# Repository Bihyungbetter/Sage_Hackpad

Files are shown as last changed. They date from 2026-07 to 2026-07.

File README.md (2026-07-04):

# Sage Hackpad

## Overview

I'm Michael, and this is my Macropad! It is inspired by the Sage Agent from Valorant. It features 10 inputs, has 9 switches, one knob, and an OLED display! 
I would like to solder it myself! 

# BOM:
- 1x Seeed XIAO RP2040
- 1x PCB
- 2x 4.7k resistor
- 9x SK6812 MINI-E LEDs
- 9x Cherry MX Switches
- 9x Through-hole 1N4148 Diodes
- 9x Blank DSA Keycaps
- 1x 0.91" 128x32 OLED Display
- 1x EC11 Rotary Encoder
- 6x M3x16mm screws
- 6x M3x5mx4mm heatset inserts

# Photos!
Master Assembly (3)
Master Assembly (4)



# Colors
If possible, could I get each part of the case in its respective colors?

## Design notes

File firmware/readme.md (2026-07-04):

# sage_hackpad

sage_hackpad

*A short description of the keyboard/project*

* Keyboard Maintainer: [Michael](https://github.com/BihyungBetter)
* Hardware Supported: *The PCBs, controllers supported*
* Hardware Availability: *Links to where you can find this hardware*

Make example for this keyboard (after setting up your build environment):

    make sage_hackpad:default

Flashing example for this keyboard:

    make sage_hackpad:default:flash

See the [build environment setup](https://docs.qmk.fm/#/getting_started_build_tools) and the [make instructions](https://docs.qmk.fm/#/getting_started_make_guide) for more information. Brand new to QMK? Start with our [Complete Newbs Guide](https://docs.qmk.fm/#/newbs).

## Bootloader

Enter the bootloader in 3 ways:

* **Bootmagic reset**: Hold down the key at (0,0) in the matrix (usually the top left key or Escape) and plug in the keyboard
* **Physical reset button**: Briefly press the button on the back of the PCB - some may have pads you must short instead
* **Keycode in layout**: Press the key mapped to `QK_BOOT` if it is available

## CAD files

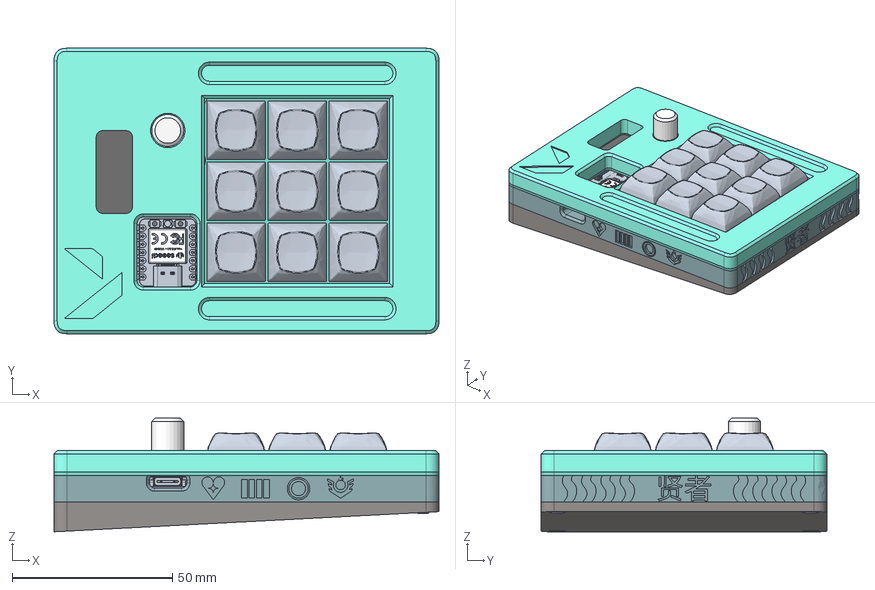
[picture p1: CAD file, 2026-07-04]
cad/Master Assembly.step
120.0 x 89.0 x 35.4 mm
MX Mount v1 x 9
DSA V4 1x1 v4 x 9
Bottom Case
92095A184_18-8 Stainless Steel Button Head Hex-Drive Screw x 4
HackPad_silkscreen x 158
D_DO-35_SOD27_P7.62mm_Horizontal_8 x 2
HackPad_copper x 36
HackPad_PCB
HackPad_soldermask x 2
D_DO-35_SOD27_P7.62mm_Horizontal_7 x 2
D_DO-35_SOD27_P7.62mm_Horizontal_5 x 2
D_DO-35_SOD27_P7.62mm_Horizontal_4 x 2
R_0805_2012Metric
R_0805_2012Metric_1
D_DO-35_SOD27_P7.62mm_Horizontal_3 x 2
D_DO-35_SOD27_P7.62mm_Horizontal_2 x 2
D_DO-35_SOD27_P7.62mm_Horizontal_1 x 2
D_DO-35_SOD27_P7.62mm_Horizontal x 2
D_DO-35_SOD27_P7.62mm_Horizontal_6 x 2
Aligner
RESC-0603_1 x 3
RESC-0603_2 x 3
RESC-0603 x 3
RESC-0603_7 x 3
2SD0601A x 4
RESC-0603_8 x 3
RESC-0603_3 x 3
Pin Header 4 x 1 TH 2.54mm Pitch x 8
RESC-0603_12 x 3
RESC-0603_9 x 3
RESC-0603_6 x 3
RESC-0603_4 x 3
RESC-0603_10 x 3
RESC-0603_5 x 3
RESC-0603_11 x 3
OLED_0.91_128x32
Seeed Studio XIAO RP2040 v26 x 36
type-c v2 x 24
VSS
VDD
main x 16
smd_button v3(Mirror)
DIN
DOUT
smd_button v3
Top Case
Middle Case
EC11-Housing-SMD x 7
EC11-Shaft-F
EC11-Base

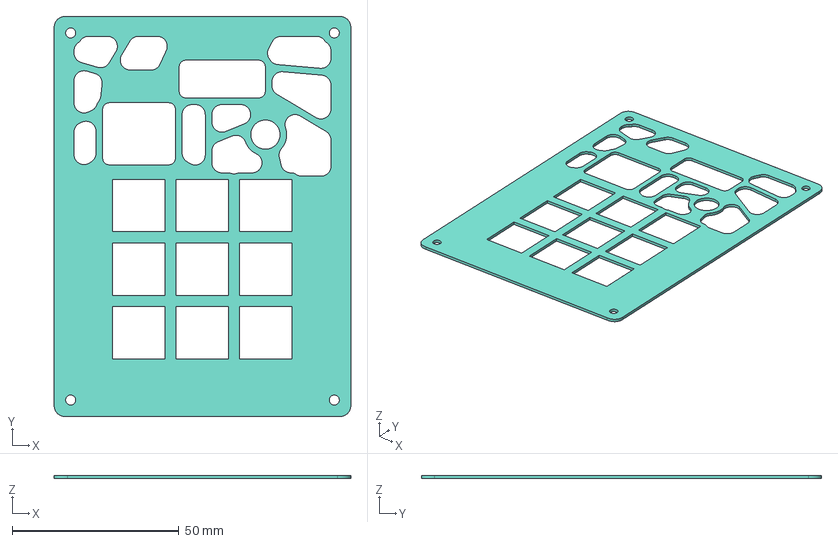
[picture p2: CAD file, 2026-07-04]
production/Part Studio 1 - Middle Case.step
89.0 x 120.0 x 1.00 mm

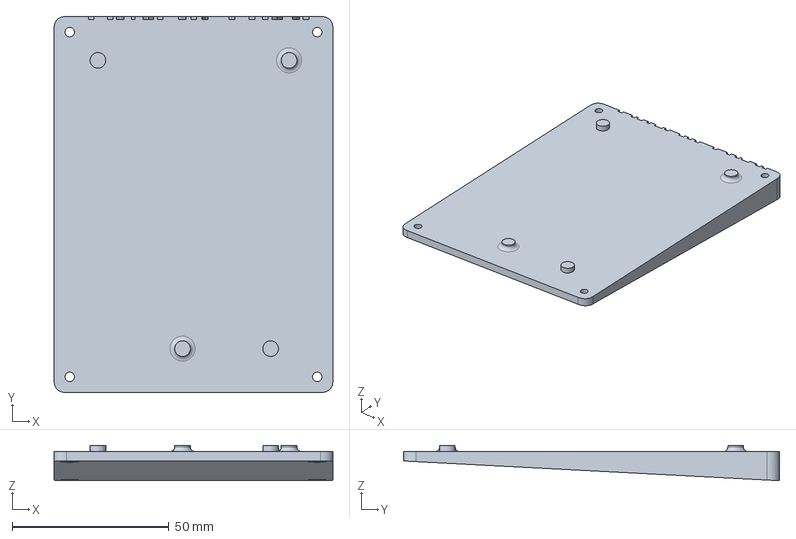
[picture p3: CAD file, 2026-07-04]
production/Part Studio 1 - Top Case.step
89.0 x 120.0 x 11.3 mm

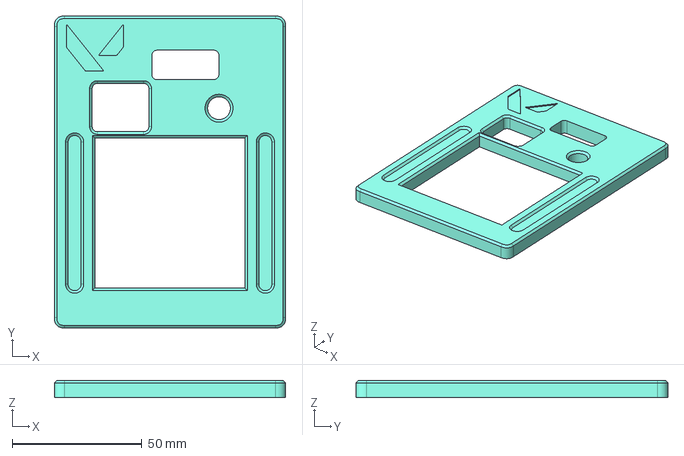
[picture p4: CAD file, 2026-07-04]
production/Part Studio 1 - Bottom Case.step
89.0 x 120.0 x 6.66 mm

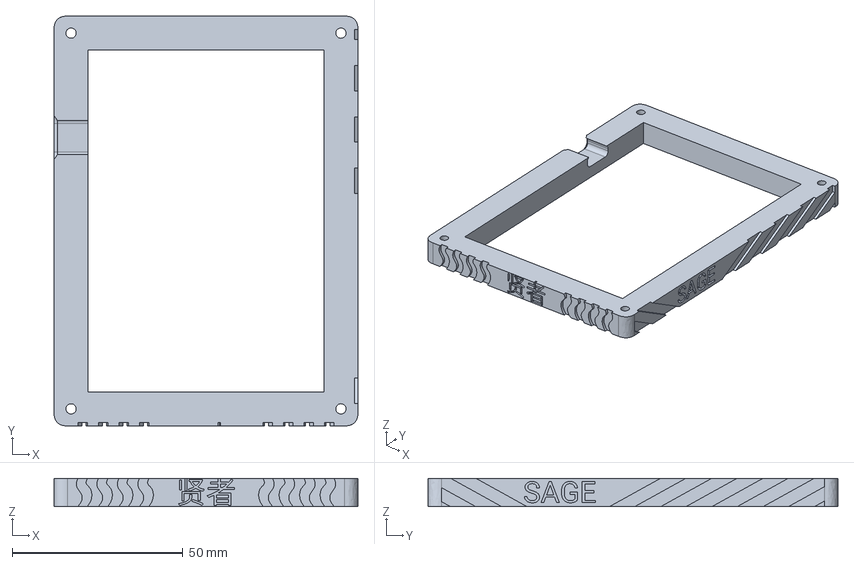
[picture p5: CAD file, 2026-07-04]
production/Part Studio 1 - Aligner.step
89.0 x 120.0 x 8.34 mm

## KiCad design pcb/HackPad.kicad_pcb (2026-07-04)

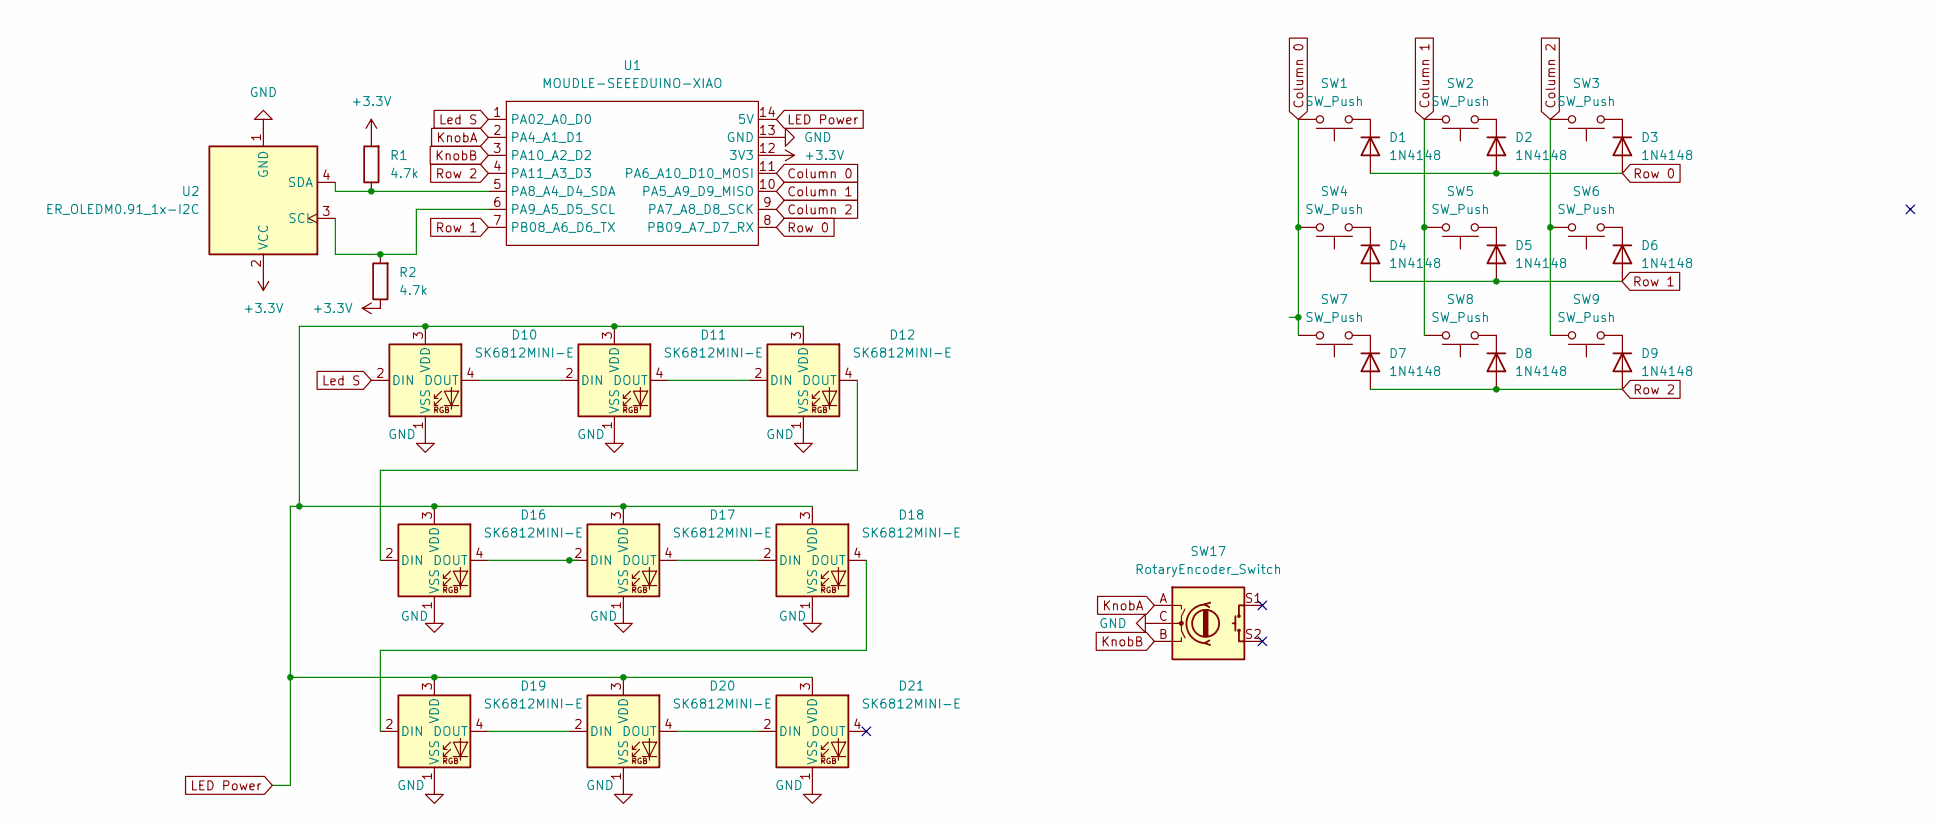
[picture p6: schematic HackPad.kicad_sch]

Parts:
D1, D2, D3, D4, D5, D6, D7, D8, D9: 1N4148; D_DO-35_SOD27_P7.62mm_Horizontal
D10, D11, D12, D16, D17, D18, D19, D20, D21: SK6812MINI-E; SK6812MINI-E_fixed
R1, R2: 4.7k; R_0805_2012Metric_Pad1.20x1.40mm_HandSolder
SW1, SW2, SW3, SW4, SW5, SW6, SW7, SW8, SW9: SW_Push; SW_Cherry_MX_1.00u_PCB
SW17: RotaryEncoder_Switch; RotaryEncoder_Alps_EC11E-Switch_Vertical_H20mm
U1: MOUDLE-SEEEDUINO-XIAO; XIAO-Generic-Hybrid-14P-2.54-21X17.8MM
U2: ER_OLEDM0.91_1x-I2C

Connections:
+3.3V: R1.2, R2.1, U1.12 (3V3), U2.2 (VCC)
Column 0: SW1.2, SW4.2, SW7.2, U1.11 (PA6_A10_D10_MOSI)
Column 1: SW2.2, SW5.2, SW8.2, U1.10 (PA5_A9_D9_MISO)
Column 2: SW3.2, SW6.2, SW9.2, U1.9 (PA7_A8_D8_SCK)
GND: D10.1 (VSS), D11.1 (VSS), D12.1 (VSS), D16.1 (VSS), D17.1 (VSS), D18.1 (VSS), D19.1 (VSS), D20.1 (VSS), D21.1 (VSS), SW17.C, U1.13 (GND), U2.1 (GND)
KnobA: SW17.A, U1.2 (PA4_A1_D1)
KnobB: SW17.B, U1.3 (PA10_A2_D2)
LED Power: D10.3 (VDD), D11.3 (VDD), D12.3 (VDD), D16.3 (VDD), D17.3 (VDD), D18.3 (VDD), D19.3 (VDD), D20.3 (VDD), D21.3 (VDD), U1.14 (5V)
Led S: D10.2 (DIN), U1.1 (PA02_A0_D0)
unnamed: D1.1 (K), SW1.1
unnamed: D2.1 (K), SW2.1
unnamed: D3.1 (K), SW3.1
unnamed: D4.1 (K), SW4.1
unnamed: D5.1 (K), SW5.1
unnamed: D6.1 (K), SW6.1
unnamed: D7.1 (K), SW7.1
unnamed: D8.1 (K), SW8.1
unnamed: D9.1 (K), SW9.1
unnamed: D10.4 (DOUT), D11.2 (DIN)
unnamed: D11.4 (DOUT), D12.2 (DIN)
unnamed: D12.4 (DOUT), D16.2 (DIN)
unnamed: D16.4 (DOUT), D17.2 (DIN)
unnamed: D17.4 (DOUT), D18.2 (DIN)
unnamed: D18.4 (DOUT), D19.2 (DIN)
unnamed: D19.4 (DOUT), D20.2 (DIN)
unnamed: D20.4 (DOUT), D21.2 (DIN)
unnamed: R1.1, U1.5 (PA8_A4_D4_SDA), U2.4 (SDA)
unnamed: R2.2, U1.6 (PA9_A5_D5_SCL), U2.3 (SCL)
Row 0: D1.2 (A), D2.2 (A), D3.2 (A), U1.8 (PB09_A7_D7_RX)
Row 1: D4.2 (A), D5.2 (A), D6.2 (A), U1.7 (PB08_A6_D6_TX)
Row 2: D7.2 (A), D8.2 (A), D9.2 (A), U1.4 (PA11_A3_D3)

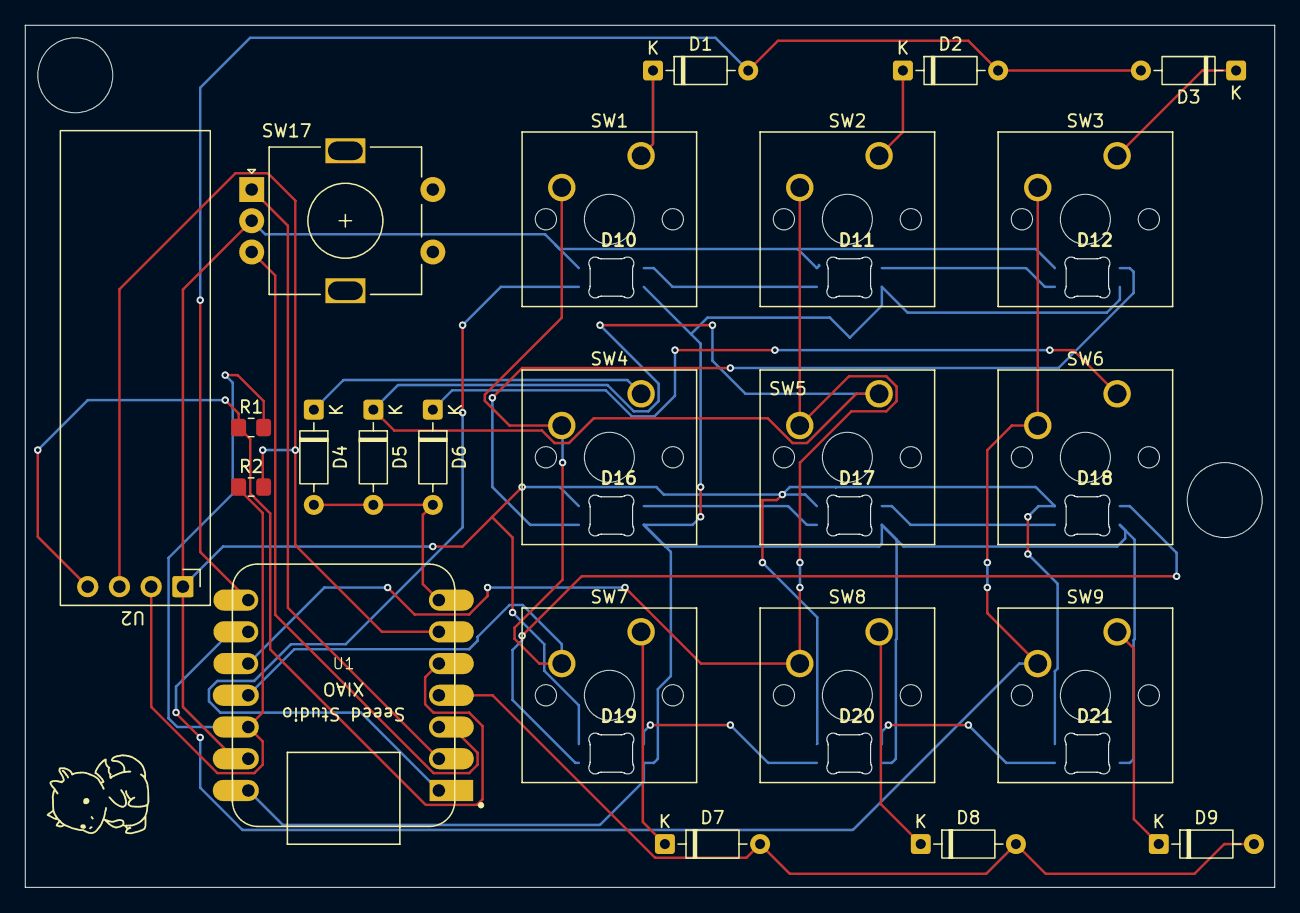
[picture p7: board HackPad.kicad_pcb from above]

Board: 2 copper layers, 100.0 x 69.0 mm, 32 parts (0 on the bottom side), 31 nets.

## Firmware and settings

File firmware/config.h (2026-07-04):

#pragma once


#define I2C_DRIVER I2CD1
#define I2C1_SDA_PIN GP6
#define I2C1_SCL_PIN GP7


#define WS2812_PIO_USE_PIO1

#define ENCODER_RESOLUTION 4

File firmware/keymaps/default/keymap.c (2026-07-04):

#include QMK_KEYBOARD_H

const uint16_t PROGMEM keymaps[][MATRIX_ROWS][MATRIX_COLS] = {
    /*  1 2 3
     *  4 5 6
     *  7 8 9
     */
    [0] = LAYOUT(
        KC_P1,   KC_P2,   KC_P3,
        KC_P4,   KC_P5,   KC_P6,
        KC_P7,   KC_P8,   KC_P9
    )
};

#if defined(ENCODER_MAP_ENABLE)
const uint16_t PROGMEM encoder_map[][NUM_ENCODERS][NUM_DIRECTIONS] = {
    [0] = { ENCODER_CCW_CW(KC_VOLD, KC_VOLU) },
};
#endif

void keyboard_post_init_user(void) {
    rgb_matrix_mode_noeeprom(RGB_MATRIX_SOLID_COLOR);
    rgb_matrix_sethsv_noeeprom(128, 255, 255); 
}


#ifdef OLED_ENABLE
bool oled_task_user(void) {
    oled_write_P(PSTR("Hackpad\n\n"), false);

    led_t led_state = host_keyboard_led_state();
    oled_write_P(led_state.num_lock ? PSTR("NUM: on\n") : PSTR("NUM: off\n"), false);

    oled_write_P(rgb_matrix_is_enabled() ? PSTR("RGB: on\n") : PSTR("RGB: off\n"), false);

    return false;
}
#endif

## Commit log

2026-07-04 adding all the CAD, PCB, and Firmware files
    [Part Studio 1 - Aligner.step, Part Studio 1 - Bottom Case.step, Part Studio 1 - Middle Case.step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]
2026-07-04 Update README with project details and BOM
    Added project overview, BOM, and color request to README.
2026-07-04 adding additional files
    [HackPad.kicad_pcb, HackPad.kicad_sch, Master Assembly.step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]
2026-10-14 Fix firmware diode direction (ROW2COL) and rebuild UF2
    The PCB places each diode's anode on the row net and the cathode toward
    the switch/column, so the matrix is ROW2COL. COL2ROW left every key
    reverse-biased and unreadable.
    Also order the middle-row RGB matrix entries to match the LED data chain
    (D16 -> D17 -> D18, left to right), and move the keymap rules.mk into
    keymaps/default/ so ENCODER_MAP_ENABLE is actually applied.
2026-10-15 Rotate key layout to match how the pad is held
    A both-direction matrix scan showed every switch reads fine (ROW2COL),
    but pressing the keys top-left to bottom-right produced 3 6 9 2 5 8 1 4 7:
    the PCB matrix is rotated 90 degrees relative to the physical layout.
    Remap LAYOUT so each physical position sends its own number, rotate the
    RGB matrix x/y positions to match, point bootmagic at the physical
    top-left key, and use KC_1..KC_9 so the keys work with Num Lock off.
2026-11-09 Drive only the three fitted LEDs (SW1, SW4, SW7) and force RGB on
    Only D10, D16 and D19 are populated, so set the RGB matrix to those three
    LEDs in chain order, and enable RGB at startup without relying on EEPROM.
2026-11-09 Drive all nine per-key LEDs
    Every SK6812MINI-E position is now populated, so the RGB matrix covers
    D10..D21 in chain order with positions matching the knob-up layout.
2026-11-09 Harden the LED data signal against the SK6812 input threshold
    The SK6812MINI-E's VIH is 0.65*VDD (~3.25V at 5V), barely below the RP2040's
    3.3V output, and QMK's RP2040 ws2812 driver leaves the data pin at the 2mA
    default drive. Marginal edges caused intermittent bit errors that showed up
    as flickering and mismatched colors down the chain.
    Drive GP26 at 12mA and use the longest in-spec high times (T0H 400ns,
    T1H 1000ns, 1.3us bit) so late-detected edges still decode correctly.
2026-11-09 Step LED brightness on host Scroll Lock toggles
    Lets the host adjust brightness at runtime (200 -> 150 -> 100 -> 50 -> 200)
    without a keymap binding or reflash.
2026-11-09 Add Spotify OLED widget and live LED control over raw HID
    Firmware: raw HID protocol for track title/artist/progress, per-LED wire-byte
    override, solid color and OLED rotation; Spotify-style 128x32 widget with
    marquee text and a progress bar; OLED stays on; default LED brightness 80.
    Host: PowerShell scripts (no installs) that find the raw HID interface,
    stream the Windows media session for Spotify, and send LED/OLED commands.
2026-11-10 Macro layout: media, Claude in VS Code, Wispr Flow, Fn layer, rainbow fade
    Base: prev/play/next, Claude Code (Ctrl+Alt+Shift+C -> Start Menu shortcut
    opening vscode://anthropic.claude-code/open), Wispr Flow push-to-talk
    (hold Ctrl+Win), mute, Fn, Snipping Tool, show desktop.
    Fn: bootloader, LED toggle/effect, Wispr paste-last and hands-free, mic mute,
    Print Screen, Task Manager; knob adjusts LED brightness. The OLED shows the
    key legend when idle and the Fn legend while Fn is held. LEDs fade through
    the rainbow.
2026-11-10 Spotify key, Sage orb idle animation, host-triggered bootloader
    Replace the Snip key with Open Spotify (Ctrl+Alt+Shift+S -> Start Menu
    shortcut). Idle OLED shows the key legend for 5s after boot, then an
    animated healing orb with orbiting particles and a flowing wave at 20fps.
    Raw HID 0xB0 0x5A 0xA5 jumps to the UF2 bootloader so the host can flash
    without a key held at plug-in (hackpad.ps1 boot).
2026-11-10 Idle OLED pets: Bongo Cat and Luna from qmk_firmware
    Replace the custom orb animation with two community animations imported by
    tools/import_pets.py (GPL-2.0-or-later, credited in pets_data.h):
    Bongo Cat (Richard Titmuss, keyboards/torn) slaps the desk on each key press,
    alternating paws; Luna (HellSingCoder, via keyboards/qck75) walks or runs
    across the screen with key activity, barks on Caps Lock, sneaks with Ctrl or
    Shift. Fn + bottom-right switches pets (replaces Task Manager).
    Also fix hackpad.ps1 sending single-packet commands one byte at a time,
    which broke boot, hsv and led-off.
2026-11-10 Switchable OLED screens: Auto, Spotify, Clock, Bongo Cat, Luna, PC stats
    Fn + bottom-right cycles screens (saved in EEPROM) with a brief name popup.
    Auto shows Spotify while music plays and Bongo Cat otherwise. The clock draws
    big 7-segment digits from host-synced time (raw HID 0x04); PC stats shows CPU
    and RAM bars (0x05). The host script becomes hackpad_agent.ps1 and also sends
    time and load.
2026-11-10 Synced lyrics screen from LRCLIB
    New Lyrics OLED screen shows the current line word-wrapped with the next line
    below. The host agent looks up each track once on lrclib.net (free, no key),
    tracks playback position, and sends the active line (raw HID 0x07/0x08) plus
    lookup status (0x09) only when it changes. Auto shows lyrics when synced
    lyrics exist, otherwise the Spotify widget, otherwise Bongo Cat.
2026-11-10 Smooth lyric ticker and pixel-smooth scrolling text
    Lyrics screen: the current line is drawn at 2x and slides across like a
    karaoke ticker, paced by the line's duration from the host (raw HID 0x0A),
    with a thin per-line progress bar; the title glides along the top. The
    next-line row is dropped. All long text (lyrics, Spotify title/artist) now
    scrolls one pixel per frame instead of jumping a character at a time.
2026-11-10 Smaller, slower lyric ticker
    Draw the current lyric at 1x so ~21 characters fit and most lines sit still;
    long lines hold 0.6s, then slide at most 30px/s, paced to the line's length.
2026-11-10 Spotify-style vertical lyrics list
    The Lyrics screen shows previous, current (inverted highlight) and the next
    two lines as a list that glides up one row over 250ms when a new line starts;
    a long current line still slides slowly within its row. The host sends the
    four lines in slots via raw HID 0x0B (replaces 0x07).
